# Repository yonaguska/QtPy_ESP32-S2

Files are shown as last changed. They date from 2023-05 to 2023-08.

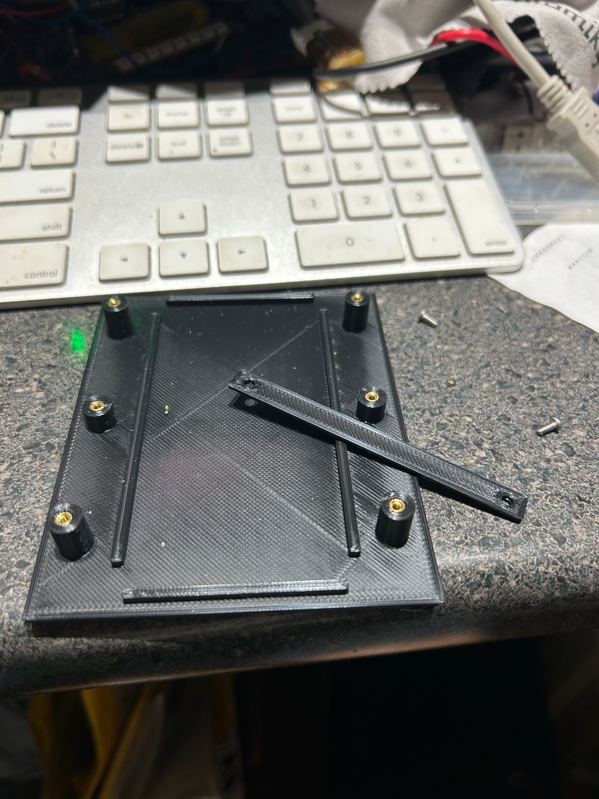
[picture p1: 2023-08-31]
printables/baseboard.png

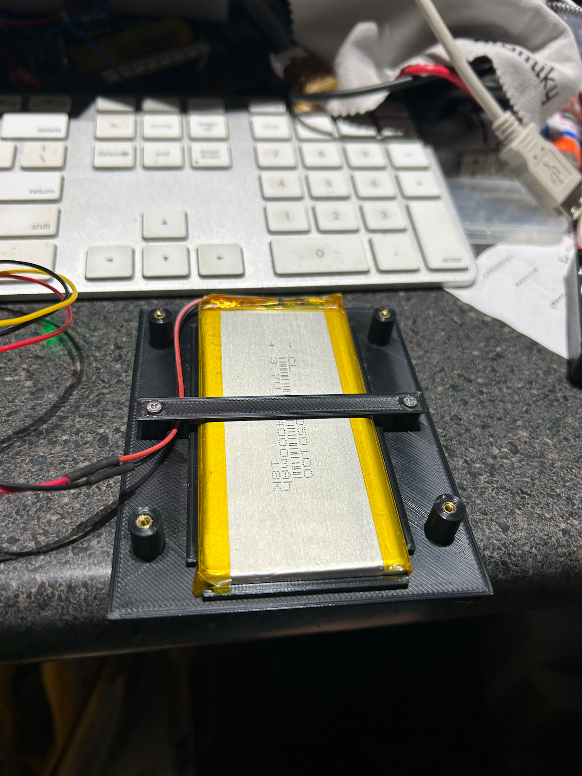
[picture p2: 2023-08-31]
printables/mounted_battery.png

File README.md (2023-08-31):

# QtPy_ESP32-S2
Adafruit QtPy ESP32 S2 used in leak detector

Kirk Franks, hobby shack 2023

This is the refactored leak detector code. I am creating modules for the
hardware aspects of the system to simplify creation and maintenance of
new and existing hardware.

The new modules include support for:
- i2c       (stemma qt and onboard)
- neopixel  (onboard indicator)
- aht20     (temp and humidity)
- sht40     (temp and humidity)
- bme280    (temp, humidity, pressure, and altitude)
- bme680    (temp, humidity, pressure, altitude, and voc/gas)
- ds3231    (timestamp, set via NTP)
- wifi      (if present)
- lc709203f (feather2 s2/s3)
- ina260    (option for testing)
- 24lc32    (4kB EEPROM on the DS3231)
- soil_probe (separate probe; power and analog input)
- battery    (external battery voltage monitor...useful for solar chargers)

The code accommodates adding hardware, detecting it, and using it automatically
It also allows the hardware to be on existing I2C pins or a STEMMA QT connector.

A typical hardware module initializes and readies the sensor, handles reading
values and making them ready for the main code.

The main code can upload values via WiFi or LoRa; modules exist for each.

This code was built for CircuitPython 8.

QtPy ESP32-S2
>>> dir(board)
    ['__class__', '__name__', 'A0', 'A1', 'A2', 'A3', 'A4', 'A5', 'A6', 'A7',
    'BOOT0', 'BUTTON', 'D0', 'D16', 'D17', 'D18', 'D35', 'D36', 'D37', 'D40',
    'D41', 'D5', 'D6', 'D7', 'D8', 'D9', 'I2C', 'MISO', 'MOSI', 'NEOPIXEL',
    'NEOPIXEL_POWER', 'RX', 'SCK', 'SCL', 'SCL1', 'SDA', 'SDA1', 'SPI',
    'STEMMA_I2C', 'TX', 'UART', 'board_id']
>>>

There's a photo, in images, showing my breadboarded prototype. The QtPy, just above the breadboard, is 
stacked with a LiPo battery charger and SD card BFFs. I use an external LiPo charger, 
shown on the breadboard with a green LED light. To the left of the breadboarded LiPo 
charger is a BME280 sensor, and just to the left of that is a DS3231 RTC with an onboard 
24LC32 memory device. To the right of the LiPo charger is a TPL5110, a timer set to a 
5 minute timeout. The TPL5110 controls the power to the QtPy's battery BFF; every 5 
minutes the TPL5110 wakes up the QtPy for processing. The QtPy processes the sensors 
and sends the data via MQTT to a Raspberry Pi RP400, which is processed for display 
by Grafana.

The RP400 has containers for eclipse-mosquitto (MQTT), telegraf (mosquitto_to_influxdb),
influxd (a time-series database), and grafana (a data visualization tool). There are 
screenshots showing portainer's view of the containers running on Docker on the RP400,
as well as graphs of the data using Grafana.

The fritzing_files directory contains files associated with prototyping and the overall
context of the project. You can breadboard the system using this information.

The images directory contains, as the name implies, photos of the prototype and finished
circuit board versions of the system.

The printables directory contains files for 3D printing a baseboard to mount the LiPo and PCB
I created for the project. The base is primarily useful for testing, but the 3D model can
be extended to create an enclosure. I've added the Fusion 360 model and STL files if you
want to fiddle with them. There are photos of this part of the project.

The backend directory has screenshots associated with the RP400-based backend containers.

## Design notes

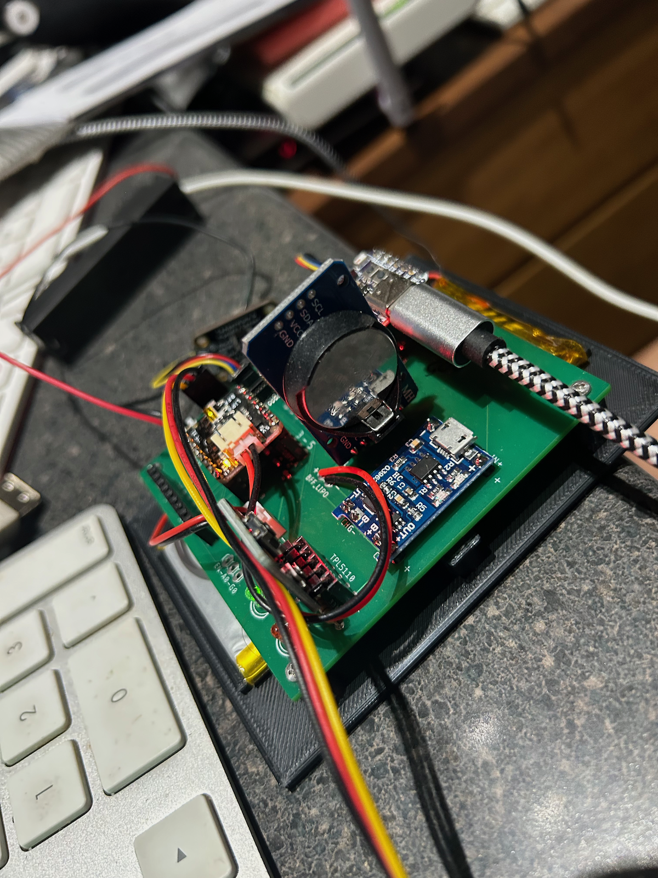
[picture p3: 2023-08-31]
images/circuit_left.png

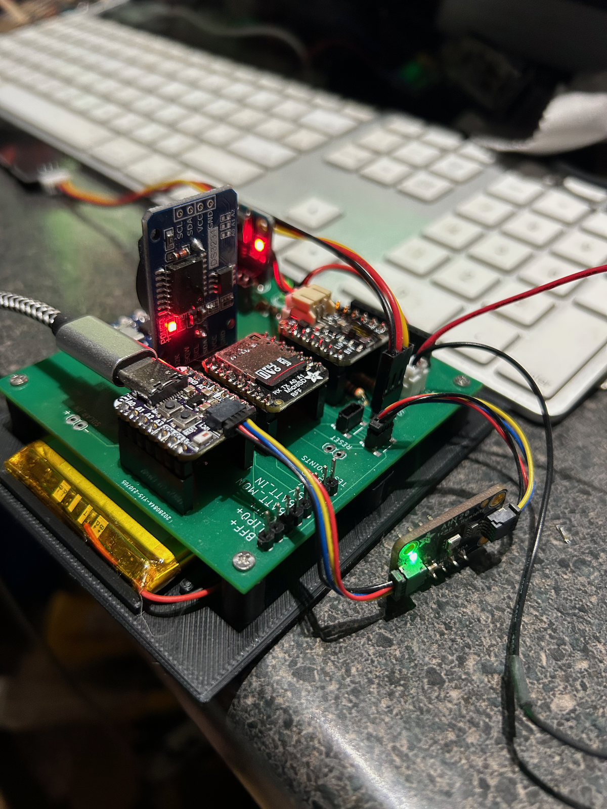
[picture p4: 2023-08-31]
images/circuit_right.png

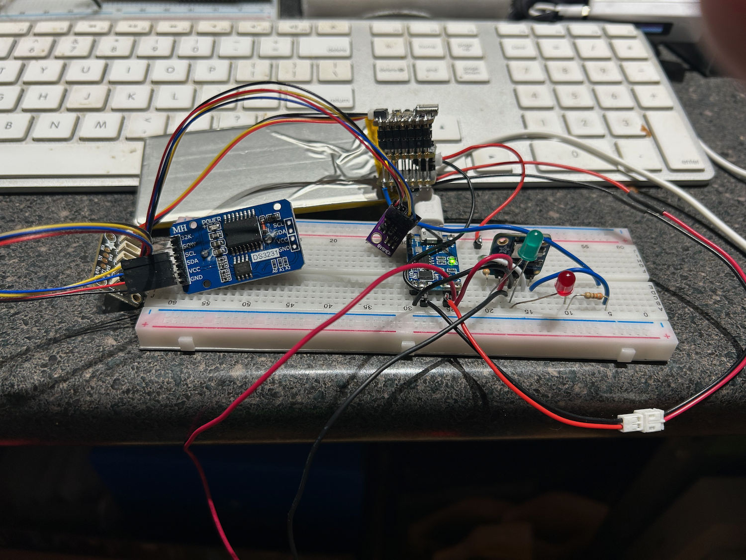
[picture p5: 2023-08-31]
images/breadboard_prototype.png

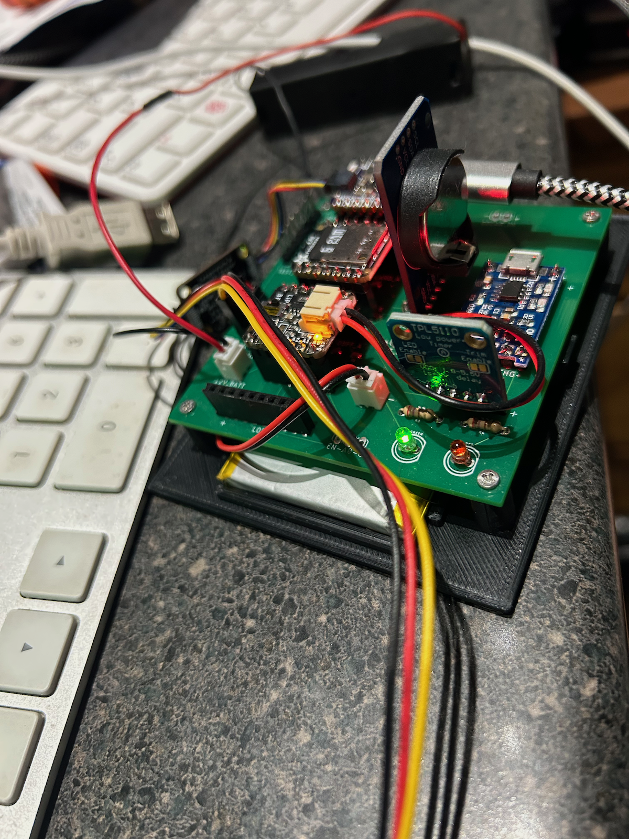
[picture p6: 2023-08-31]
images/circuit_rear.png

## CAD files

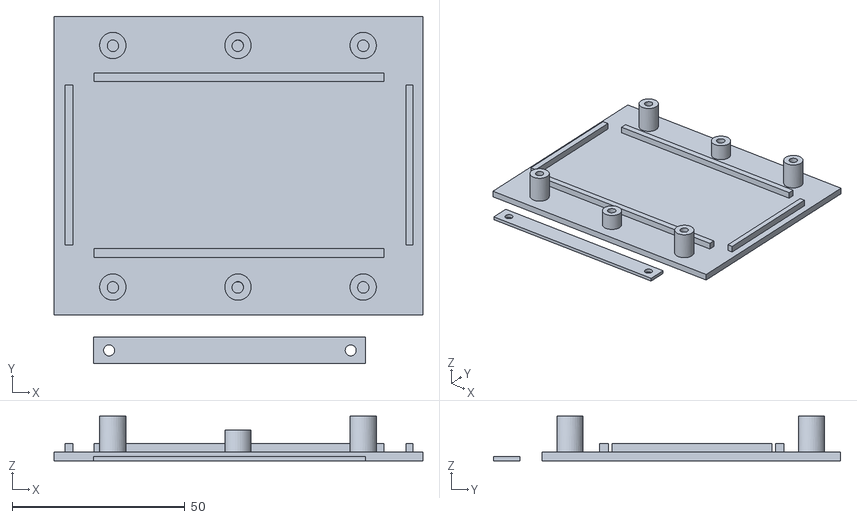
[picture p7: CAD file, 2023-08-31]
printables/tpl5110-2 v19.stl
106.7 x 100.4 x 13.0

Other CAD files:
printables/tpl5110-2 v19.f3d

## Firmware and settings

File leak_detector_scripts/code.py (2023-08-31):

'''
   Kirk Franks, hobby shack 2023

   This is the refactored leak detector code. I am creating modules for the
   hardware aspects of the system to simplify creation and maintenance of
   new and existing hardware.

   The new modules include support for:
   - i2c        (stemma qt and onboard)
   - neopixel   (onboard indicator)
   - aht20      (temp and humidity)
   - sht40      (temp and humidity)
   - bme280     (temp, humidity, pressure, and altitude)
   - bme680     (temp, humidity, pressure, altitude, and voc/gas)
   - ds3231     (timestamp, set via NTP)
   - wifi       (if present)
   - lc709203f  (feather2 s2/s3)
   - ina260     (option for testing)
   - 24lc32     (4kB EEPROM on the DS3231)
   - soil_probe (separate probe; power and analog input)
   - battery    (external battery voltage monitor...useful for solar chargers)

   The code accommodates adding hardware, detecting it, and using it automatically
   It also allows the hardware to be on existing I2C pins or a STEMMA QT connector.

   A typical hardware module initializes and readies the sensor, handles reading
   values and making them ready for the main code.

   The main code can upload values via WiFi or LoRa; modules exist for each.

   This code was built for CircuitPython 8.

   QtPy ESP32-S2
   >>> dir(board)
       ['__class__', '__name__', 'A0', 'A1', 'A2', 'A3', 'A4', 'A5', 'A6', 'A7',
       'BOOT0', 'BUTTON', 'D0', 'D16', 'D17', 'D18', 'D35', 'D36', 'D37', 'D40',
       'D41', 'D5', 'D6', 'D7', 'D8', 'D9', 'I2C', 'MISO', 'MOSI', 'NEOPIXEL',
       'NEOPIXEL_POWER', 'RX', 'SCK', 'SCL', 'SCL1', 'SDA', 'SDA1', 'SPI',
       'STEMMA_I2C', 'TX', 'UART', 'board_id']
>>>
'''

# SPDX-FileCopyrightText: 2021 ladyada for Adafruit Industries
# SPDX-License-Identifier: MIT
# standard libraries
import os
import re
import alarm
import time
import ssl
import socketpool

# standard CircuitPython libraries
import busio
import microcontroller
import watchdog
import wifi
import storage
import board
#from board import A0  # ADC/DAC, used as digital VCC for soil probe
from board import A1  # ADC/DAC 12v Battery monitor 12k-3k divider
from board import A2  # ADC QtPy BFF battery voltage
#from board import A3  # ADC for soil probe
import digitalio
from digitalio import DigitalInOut
import analogio
from analogio import AnalogIn

# Adafruit libraries
import adafruit_minimqtt.adafruit_minimqtt as MQTT
import adafruit_sdcard
import adafruit_logging as logging
from adafruit_logging import FileHandler
from adafruit_lc709203f import LC709203F
from adafruit_io.adafruit_io import IO_MQTT
from adafruit_simplemath import map_range

# my libraries
import mod_neopixel
import mod_i2c
import mod_aht20
import mod_sht40
import mod_bme280
import mod_bme680
import mod_ina260
import mod_ds3231
import mod_24lc32
import mod_soil_probe
import mod_battery_voltage


""" basic global variables ... very important!!! """
version = 8.5 # Working copy with sensors, RTC w/NTP, soil_probe, external battery probe, and talks to MQTT via Wifi
code_status = "work in progress"
sleep_time = 60 * 5 #  sleep_time = 60 * 5   .... or 60 for testing
watchdog_timeout = sleep_time + 30
debug = True
connect_to_wifi = True  # False for debugging
do_connect_to_broker = True
do_send_to_broker = True
ic2_connected = False
i2c_qwiic_connected = False
model = "qtpy"  # or qtpy/featherS2/featherS3
using_bff = True
test_watchdog = False
reset_wait_time = 300
reload_wait_time = 300
charger = "bff"  # or solar/bff
using_hardware_watchdog = True
hardware_reset_duration = 0.1
trigger_duration = 0.2
error_sleep = sleep_time
sd_card = False
soil_moisture_detector_used = True
battery_probe_used = True
sd_card_used = True
testing_wdt = False
set_ds3231 = False   # <<<<<<<<<<< IF YOU NEED TO SET THE RTC, USING NTP >>>>>>>>


""" FUNCTIONS """
# The print function....also logs
def my_print(level, message, end=''):
    U_level = level.upper()
    mod_message = "{}: {}".format(U_level, message)
    print("{}".format(mod_message))
    if sdcard_filesystem:
        if level == "debug":
            logger.debug(mod_message)
        elif level == "info":
            logger.info(mod_message)
        elif level == "warning":
            logger.warning(mod_message)
        elif level == "error":
            logger.error(mod_message)
        elif level == "critical":
            logger.critical(mod_message)
        else:
            logger.debug(mod_message)


# This helper function will print the contents of the SD
def print_directory(path, tabs=0):
    print("Files on filesystem:")
    print("====================")
    for file in os.listdir(path):
        stats = os.stat(path + "/" + file)
        filesize = stats[6]
        isdir = stats[0] & 0x4000

        if filesize < 1000:
            sizestr = str(filesize) + " bytes"
        elif filesize < 1000000:
            sizestr = "%0.1f KB" % (filesize / 1000)
        else:
            sizestr = "%0.1f MB" % (filesize / 1000000)

        prettyprintname = ""
        for _ in range(tabs):
            prettyprintname += "   "
        prettyprintname += file
        if isdir:
            prettyprintname += "/"
        print("{0:<40} Size: {1:>10}".format(prettyprintname, sizestr))

        # recursively print directory contents
        if isdir:
            print_directory(path + "/" + file, tabs + 1)


def get_voltage(pin):
    return (pin.value * 3.3) / 65536


def deep_sleep(this_sleep_time):
    """ Do a deep sleep to conserve battery and close logger file handle """
    # prepare and sleep
    time_alarm = alarm.time.TimeAlarm(monotonic_time=time.monotonic() + this_sleep_time)
    alarm.exit_and_deep_sleep_until_alarms(time_alarm)


""" MQTT related callbacks """
# Define callback methods which are called when events occur
# pylint: disable=unused-argument, redefined-outer-name
def connect(mqtt_client, userdata, flags, rc):
    # This function will be called when the mqtt_client is connected
    # successfully to the broker.
    my_print("info" ,"Connected to MQTT Broker!")
    my_print("info" ,"Flags: {0}\n RC: {1}".format(flags, rc))


def disconnect(mqtt_client, userdata, rc):
    # This method is called when the mqtt_client disconnects
    # from the broker.
    my_print("info" ,"Disconnected from MQTT Broker!")


def subscribe(mqtt_client, userdata, topic, granted_qos):
    # This method is called when the mqtt_client subscribes to a new feed.
    my_print("info" ,"Subscribed to {0} with QOS level {1}".format(topic, granted_qos))


def unsubscribe(mqtt_client, userdata, topic, pid):
    # This method is called when the mqtt_client unsubscribes from a feed.
    my_print("info" ,"Unsubscribed from {0} with PID {1}".format(topic, pid))


def publish(mqtt_client, userdata, topic, pid):
    # This method is called when the mqtt_client publishes data to a feed.
    #my_print("info" ,"Published to {0} with PID {1}".format(topic, pid))
    pass
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

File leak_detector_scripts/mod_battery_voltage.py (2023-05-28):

import time
import board
import digitalio
import analogio
from board import A1
from adafruit_simplemath import map_range

def get_voltage(pin):
    return (pin.value * 3.3) / 65536

def init(model):
    probe_ready = False
    ## Power pin for soil moisture detector
    if (model == "featherS2") or (model == "featherS3"):
        adc = analogio.AnalogIn(A1)
        probe_ready = True
    if (model == "qtpy"):
        adc = analogio.AnalogIn(A1)
        probe_ready = True
    return probe_ready, adc

def read(adc):
    # Power up the soil probe and let it stabilize before taking reading
    time.sleep(1)
    divider_reading = 1.0 * get_voltage(adc)
    battery_voltage = map_range(divider_reading, 0.032 , 3.2, 0.0, 16.0)
    # Power down the soil probe
    sensor_data = {
    	"type":  "battery",
        "divider_reading": divider_reading,
        "battery_voltage": battery_voltage
             }
    return sensor_data

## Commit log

2023-05-28 modified comments
    Modified comments in header to reflect soil and battery monitors
2023-05-30 Fritzing
    Adding fritzing information
    [QtPy-ESP32S2 2.fzz, QtPy-ESP32S2 3.fzz]
2023-08-31 new structure
    Added directories and shuffled files to make repository more presentable
    [QtPy-ESP32S2 2.fzz, QtPy-ESP32S2 3.fzz]
2023-08-31 collecting images
    Collection of images for project
    [tpl5110-2 v19.f3d, tpl5110-2 v19.stl]
